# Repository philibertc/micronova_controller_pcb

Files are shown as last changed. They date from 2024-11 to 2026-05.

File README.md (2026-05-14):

# micronova_controller_pcb
The repo for the PCB made to work with the micronova_controller project. Software details [here.](https://github.com/philibertc/micronova_controller/)


<a href="https://www.tindie.com/products/philibertc/pellet-heater-controller/">
  I sell on Tindie
</a>
<a href="https://www.paypal.com/donate?hosted_button_id=Q48QBGGQTVGTG">
  Donate with PayPal
</a>

**Kits are available on Tindie!**  
**_In stock every month._**  
**Here is an overview of the additions:**

- **possibility to reset the settings with a flat screwdriver**
- **IO footprints are now designed to accept screw terminals**
- **D0 and RST are connected for deep sleep**
- **a row of pins has been added to access unused pins**

## License
<br />This work is licensed under a <a rel="license" href="http://creativecommons.org/licenses/by-nc-nd/4.0/">Creative Commons Attribution-NonCommercial-NoDerivatives 4.0 International License</a>.

## Working with
stoves equipped with Micronova mainboard.
<details>
<summary><b>Known brands</b></summary>

- AMG S.p.A. (Artel, Kalor, Tepor, Foco, Adler)
- Anselmo Cola
- Boreal
- Bronpi
- Cadel
- Clam
- Corisit S.r.l. (Lincar, Vulcania, Arce)
- Ecoteck
- EL.FIRE
- EOSS
- EvaCalor
- Fontana Calore
- Fonte Flamme
- Galletti
- Globe-Fire
- Italiana Camini
- Jolly Mec
- Karmek
- Kepo
- Klover
- Laminox
- LMX
- La Nordica S.p.A (Extraflame, Dal Zotto)
- Lorflam
- MCZ (Brisach, Cadel, FreePoint, Pegaso, Red)
- Moretti Design
- Nordic Fire
- Palladio
- Piazetta
- Sicalor
- Stufe a pellet Italia
- Tecnoflam
- Termoflam
- Thermoflux
- TS
- Ungaro
- Zibro
</details>

## Confirmed working with
<details>
<summary><b>Known models</b></summary>

- RED Loto
- MCZ Kaika/Face
- FreePoint Sharp
- Anselmo Cola Aloe
- Kalor Compact (boiler, fumesTempAddr 0xFF, flamePowerAddr 0x37)
- ITC Layma (boiler, fumesTempAddr 0x5A, no water pressure value available)
- Piazetta P958D
- Piazetta Line
- ETNA Giulia EVO (Micronova J042, fumes temp and power reading doesn't work for the moment)
- Extraflame Teodora Evo (at least turning on works)
- El.Fire Venice Slim
- Palladio Europa
</details>

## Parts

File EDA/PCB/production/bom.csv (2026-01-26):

Designator | Footprint | Quantity | Value | LCSC Part #
J1 | PinSocket_1x10_P2.54mm_Vertical | 1 | Conn_01x10
J2 | PinSocket_1x02_P2.54mm_Vertical | 1 | Conn_01x02_Pin
J3 | PinSocket_1x03_P2.54mm_Vertical | 1 | Conn_01x03_Pin
J4 | TerminalBlock_bornier-2_P5.08mm | 1 | Screw_Terminal_01x02
J5 | TerminalBlock_bornier-3_P5.08mm | 1 | Screw_Terminal_01x03
R1, R2, R3 | R_Axial_DIN0207_L6.3mm_D2.5mm_P10.16mm_Horizontal | 3 | 470
R4 | R_Axial_DIN0207_L6.3mm_D2.5mm_P10.16mm_Horizontal | 1 | 10k
TP1, TP2 | TestPoint_Pad_1.5x1.5mm | 2 | TestPoint_Flag
TP3, TP4 | TestPoint_Pad_1.0x1.0mm | 2 | TestPoint
U1 | WEMOS_D1_mini_light | 1 | WeMos_D1_mini
U2, U3, U4 | DIP-4_W7.62mm | 3 | PC817

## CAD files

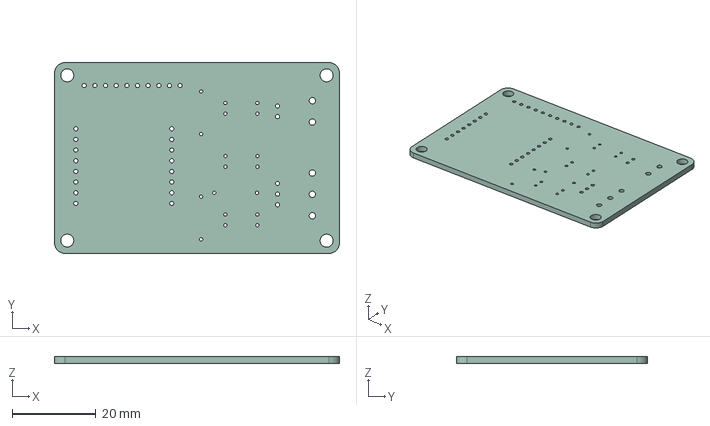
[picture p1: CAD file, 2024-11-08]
EDA/PCB/PCB.step
67.9 x 45.5 x 1.60 mm

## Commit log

2022-09-03 Adding EDA files
    [PCB-B_Cu.gbl, PCB-B_Mask.gbs, PCB-B_Paste.gbp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]
2022-09-03 Minor PCB changes
    [PCB-B_Cu.gbl, PCB-B_Mask.gbs, PCB-B_Paste.gbp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]
2023-01-25 v1.3 (v3 of first iteration)
    [PCB-rounded.kicad_pcb]
2023-01-27 size corrections
    [PCB.kicad_pcb]
2024-10-25 Add ground plane
    [PCB.kicad_pcb, PCB.kicad_sch]
2024-10-25 Ready for prod
    [PCB.kicad_pcb, bom.csv, designators.csv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]
2024-10-25 Correcting silkscreen errors
    rev1.4
    [PCB.kicad_pcb, PCB.kicad_sch, bom.csv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]
2024-11-08 Adding step file
    [PCB.step]
2025-10-12 Adding the possibilty the use D1 as RX_h
    Adding the 10k external pullout
    https://github.com/philibertc/micronova_controller/issues/31
    [PCB.kicad_pcb, PCB.kicad_sch]
2026-01-26 Gerber for pcb v1.5
    [bom.csv, designators.csv, positions.csv]
